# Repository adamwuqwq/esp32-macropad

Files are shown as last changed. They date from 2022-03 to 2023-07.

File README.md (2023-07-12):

# macropad

## Introduction
A low-budget macro numeric keypad based on ESP32 MCU and CH9329 USB HID emulation chip.  

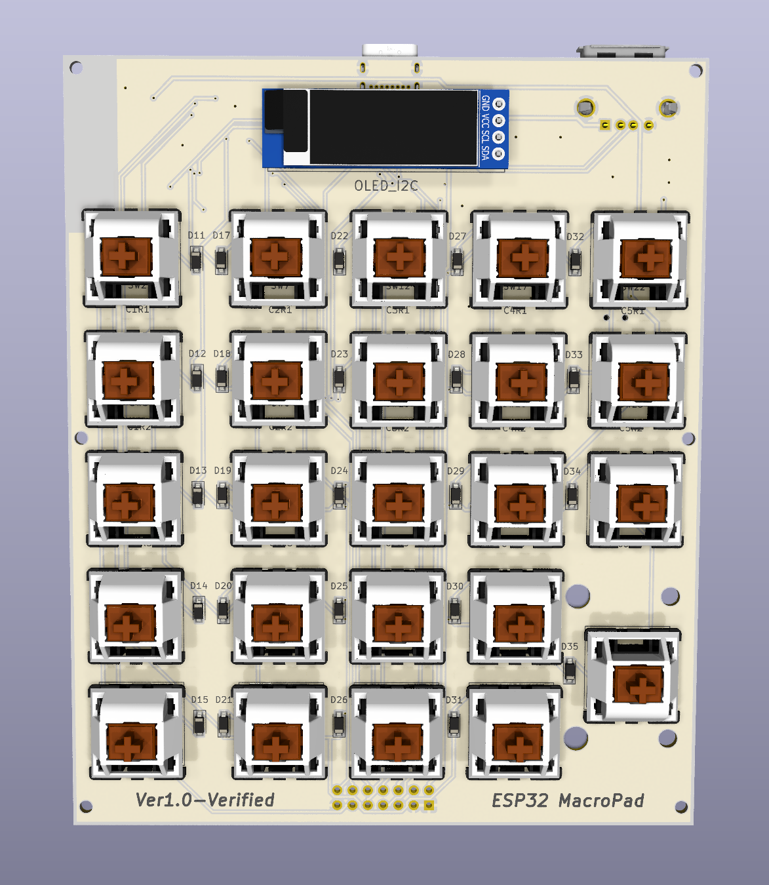
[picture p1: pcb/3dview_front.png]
Image of PCB


## Functions
### Keys and Layout
1. Standard 10-key layout + 5 function keys
2. All key macro support
3. Up to 5 macro profiles (stored in MCU's internal storage)

### Connectivity
1. USB 2.0 HID (CH9329 based) 
2. Built-in USB hub, 1 external USB port, 1 internal USB (based on FE1.1s)
3. USB UART debugging (based on CH340C)
4. Bluetooth 4.2 BLE HID   
5. 2.4GHz Wi-Fi (for configuration and OTA firmware update)

### Power Supply & Power Management
1. 3.7V Li-ion battery charging and management (based on TP5400)
2. Supports MCU's deep sleep and hibernation. 

### UI & User Interaction
1. 0.91' built-in I2C OLED screen
2. Cross-platform configuration App on PC using Qt/PyQt
3. Web configuration interface

### Others
1. USB HID Mouse emulation
2. TBD

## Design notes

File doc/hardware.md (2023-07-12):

# Documentation about the hardware

## System Architecture Diagram
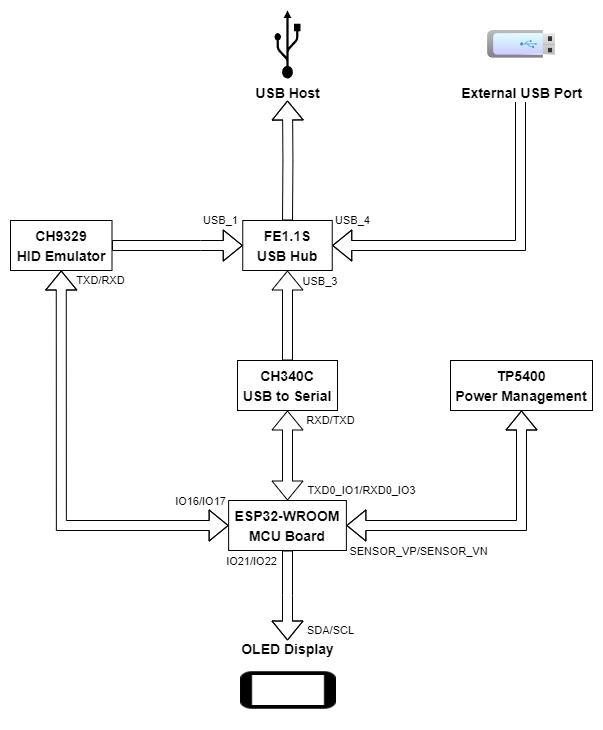
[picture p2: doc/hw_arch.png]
System Architecture


## ESP32 MCU Port Mapping
|Port Name|Connected to|
|--|--|
|KeyMatrix_ROW
|IO27|KeyMatrix row 1|
|IO32|KeyMatrix row 2|
|IO33|KeyMatrix row 3|
|IO25|KeyMatrix row 4|
|IO26|KeyMatrix row 5|
|KeyMatrix_COL
|IO5|KeyMatrix column 1|
|IO18|KeyMatrix column 2|
|IO19|KeyMatrix column 3|
|IO23|KeyMatrix column 4|
|IO4|KeyMatrix column 5|
|OLED_I2C
|IO21|OLED display SDA|
|IO22|OLED display SCL|
|CH9329_HID
|IO16|CH9329 chip TXD|
|IO17|CH9329 chip RXD|
|TP5400_BATT
|SENSOR_VP / IO36|Battery voltage ADC|
|IO39 / SENSOR_VN|Charging indicator|
|CH340_SER
|TXD0 / IO1|CH340 chip RXD|
|RXD0 / IO3|CH340 chip TXD|

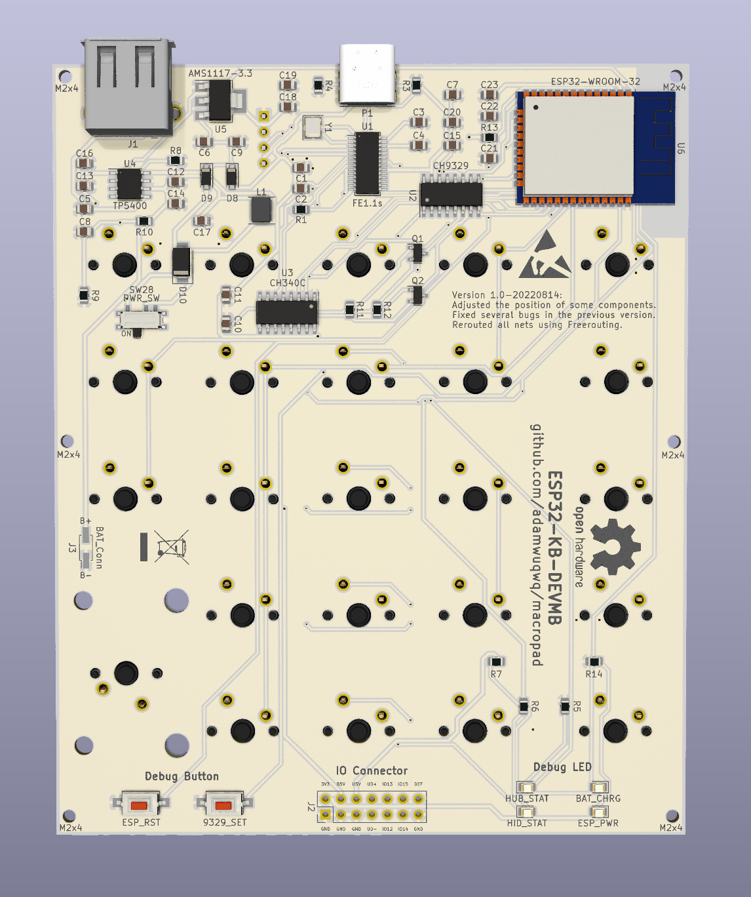
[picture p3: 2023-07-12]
pcb/3dview_back.png

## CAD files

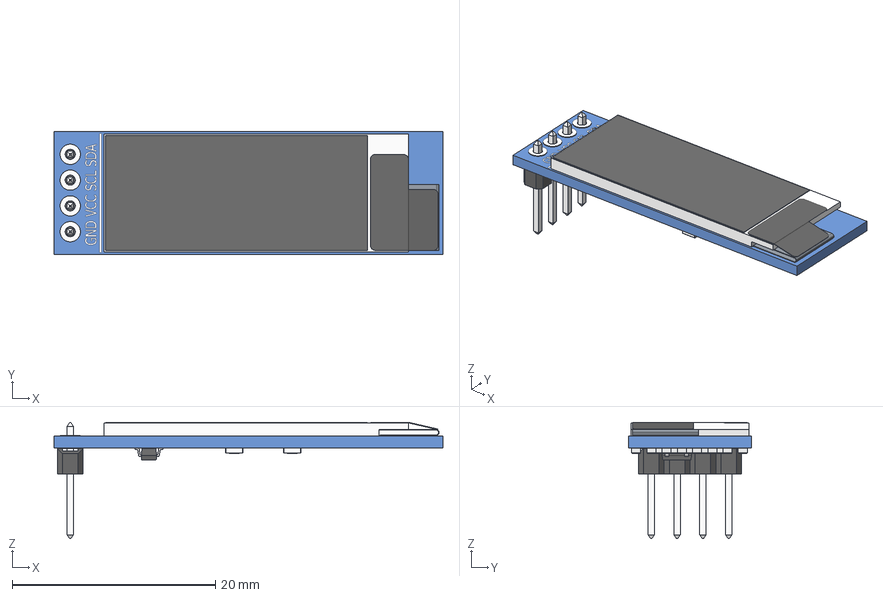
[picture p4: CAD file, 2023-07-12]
pcb/3dmodel/OLED_0.91_128x32.stp
38.3 x 12.1 x 11.5 mm
OLED_0.91_128x32
Pin Header 4 x 1 TH 2.54mm Pitch
RESC-0603 x 13
2SD0601A

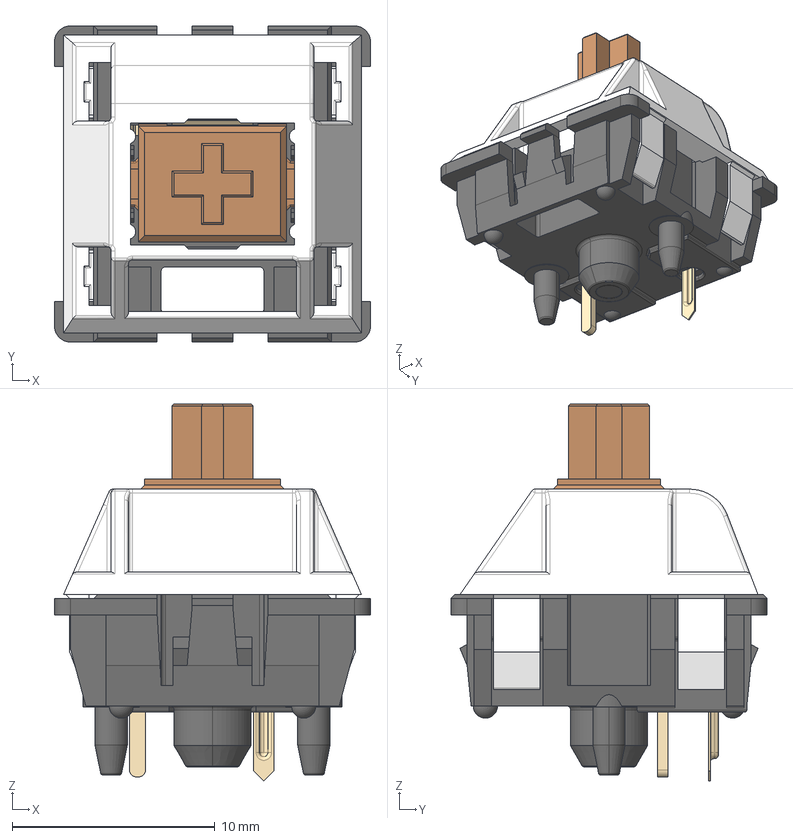
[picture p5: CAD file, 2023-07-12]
pcb/3dmodel/SW_Cherry_MX_PCB.stp
15.6 x 15.6 x 18.6 mm

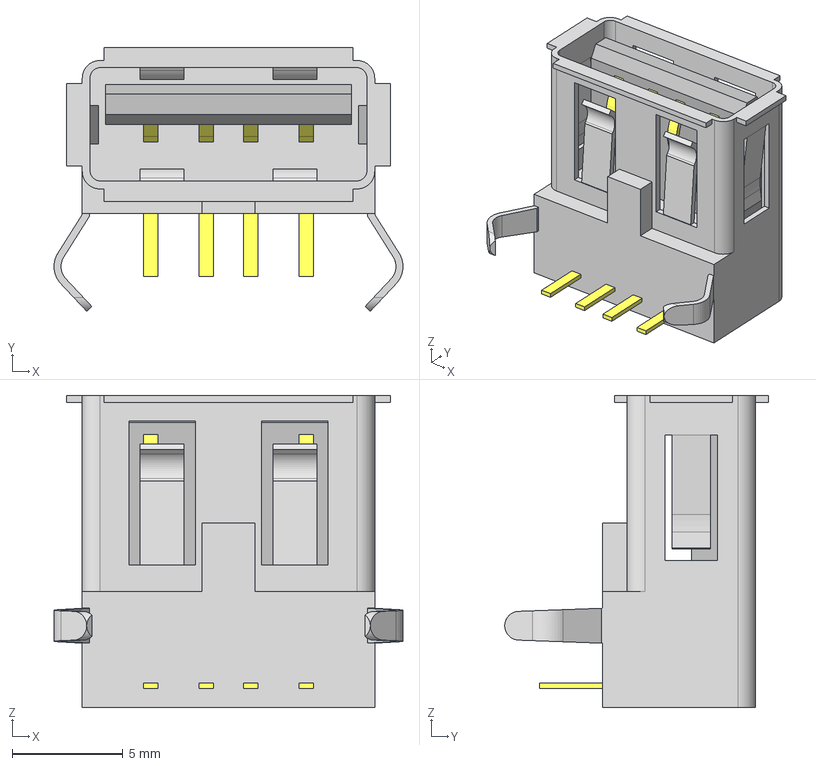
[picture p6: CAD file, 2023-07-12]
pcb/3dmodel/USB-A-S-F-B-TH.stp
15.7 x 11.9 x 14.1 mm
USB-A-S-TH_P
USB-A-S-B-TH_B
USB-A-S-TH_S

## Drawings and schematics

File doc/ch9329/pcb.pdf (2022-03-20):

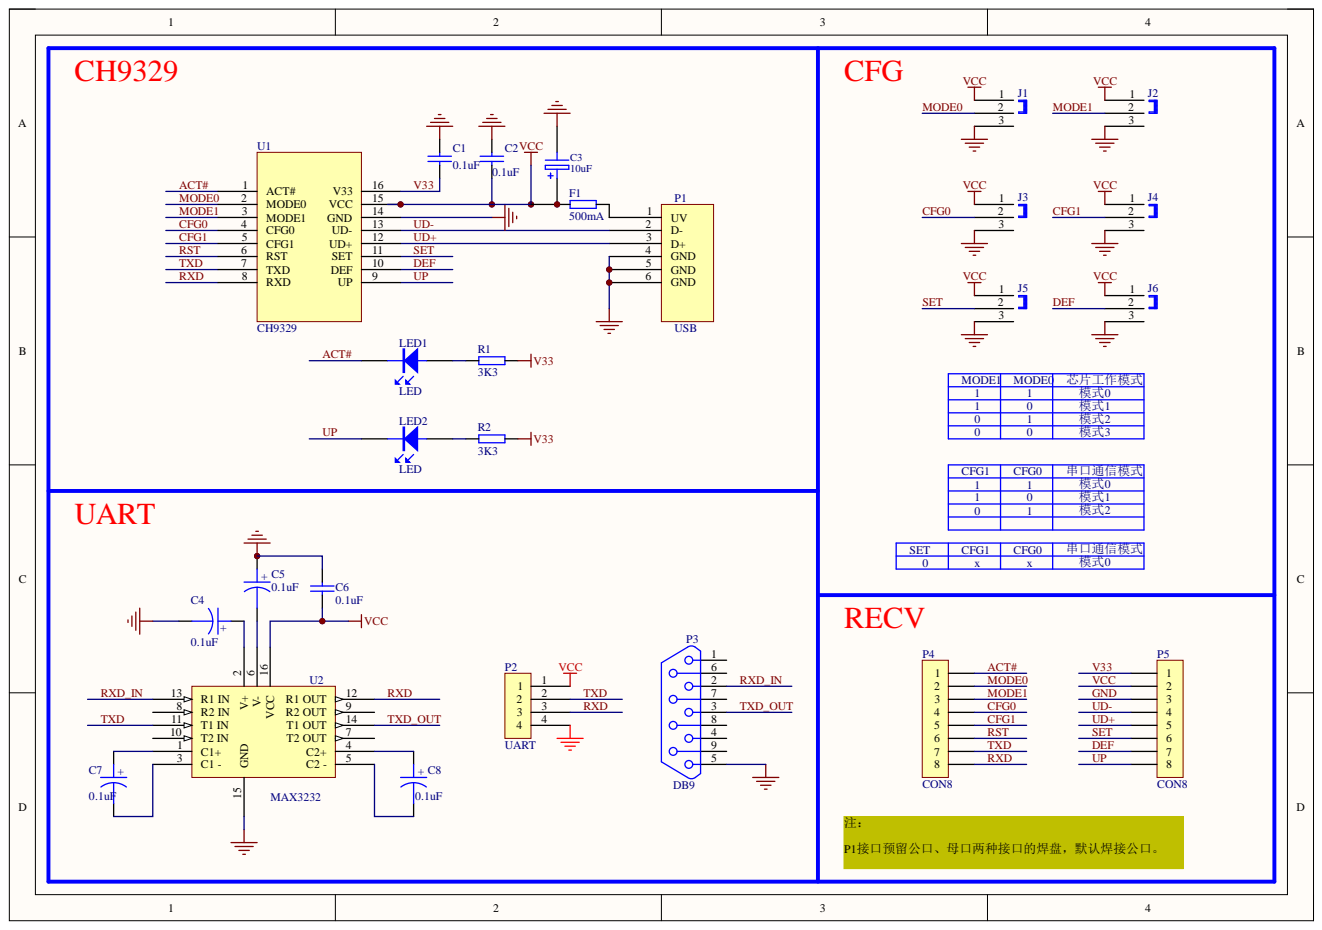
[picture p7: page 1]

MODE1 MODE0 芯片工作模式
1 | 1 | 模式0
1 | 0 | 模式1
0 | 1 | 模式2
0 | 0 | 模式3

CFG1 | CFG0 | 串口通信模式

SET | CFG1 | CFG0 | 串口通信模式
0 | x | x | 模式0

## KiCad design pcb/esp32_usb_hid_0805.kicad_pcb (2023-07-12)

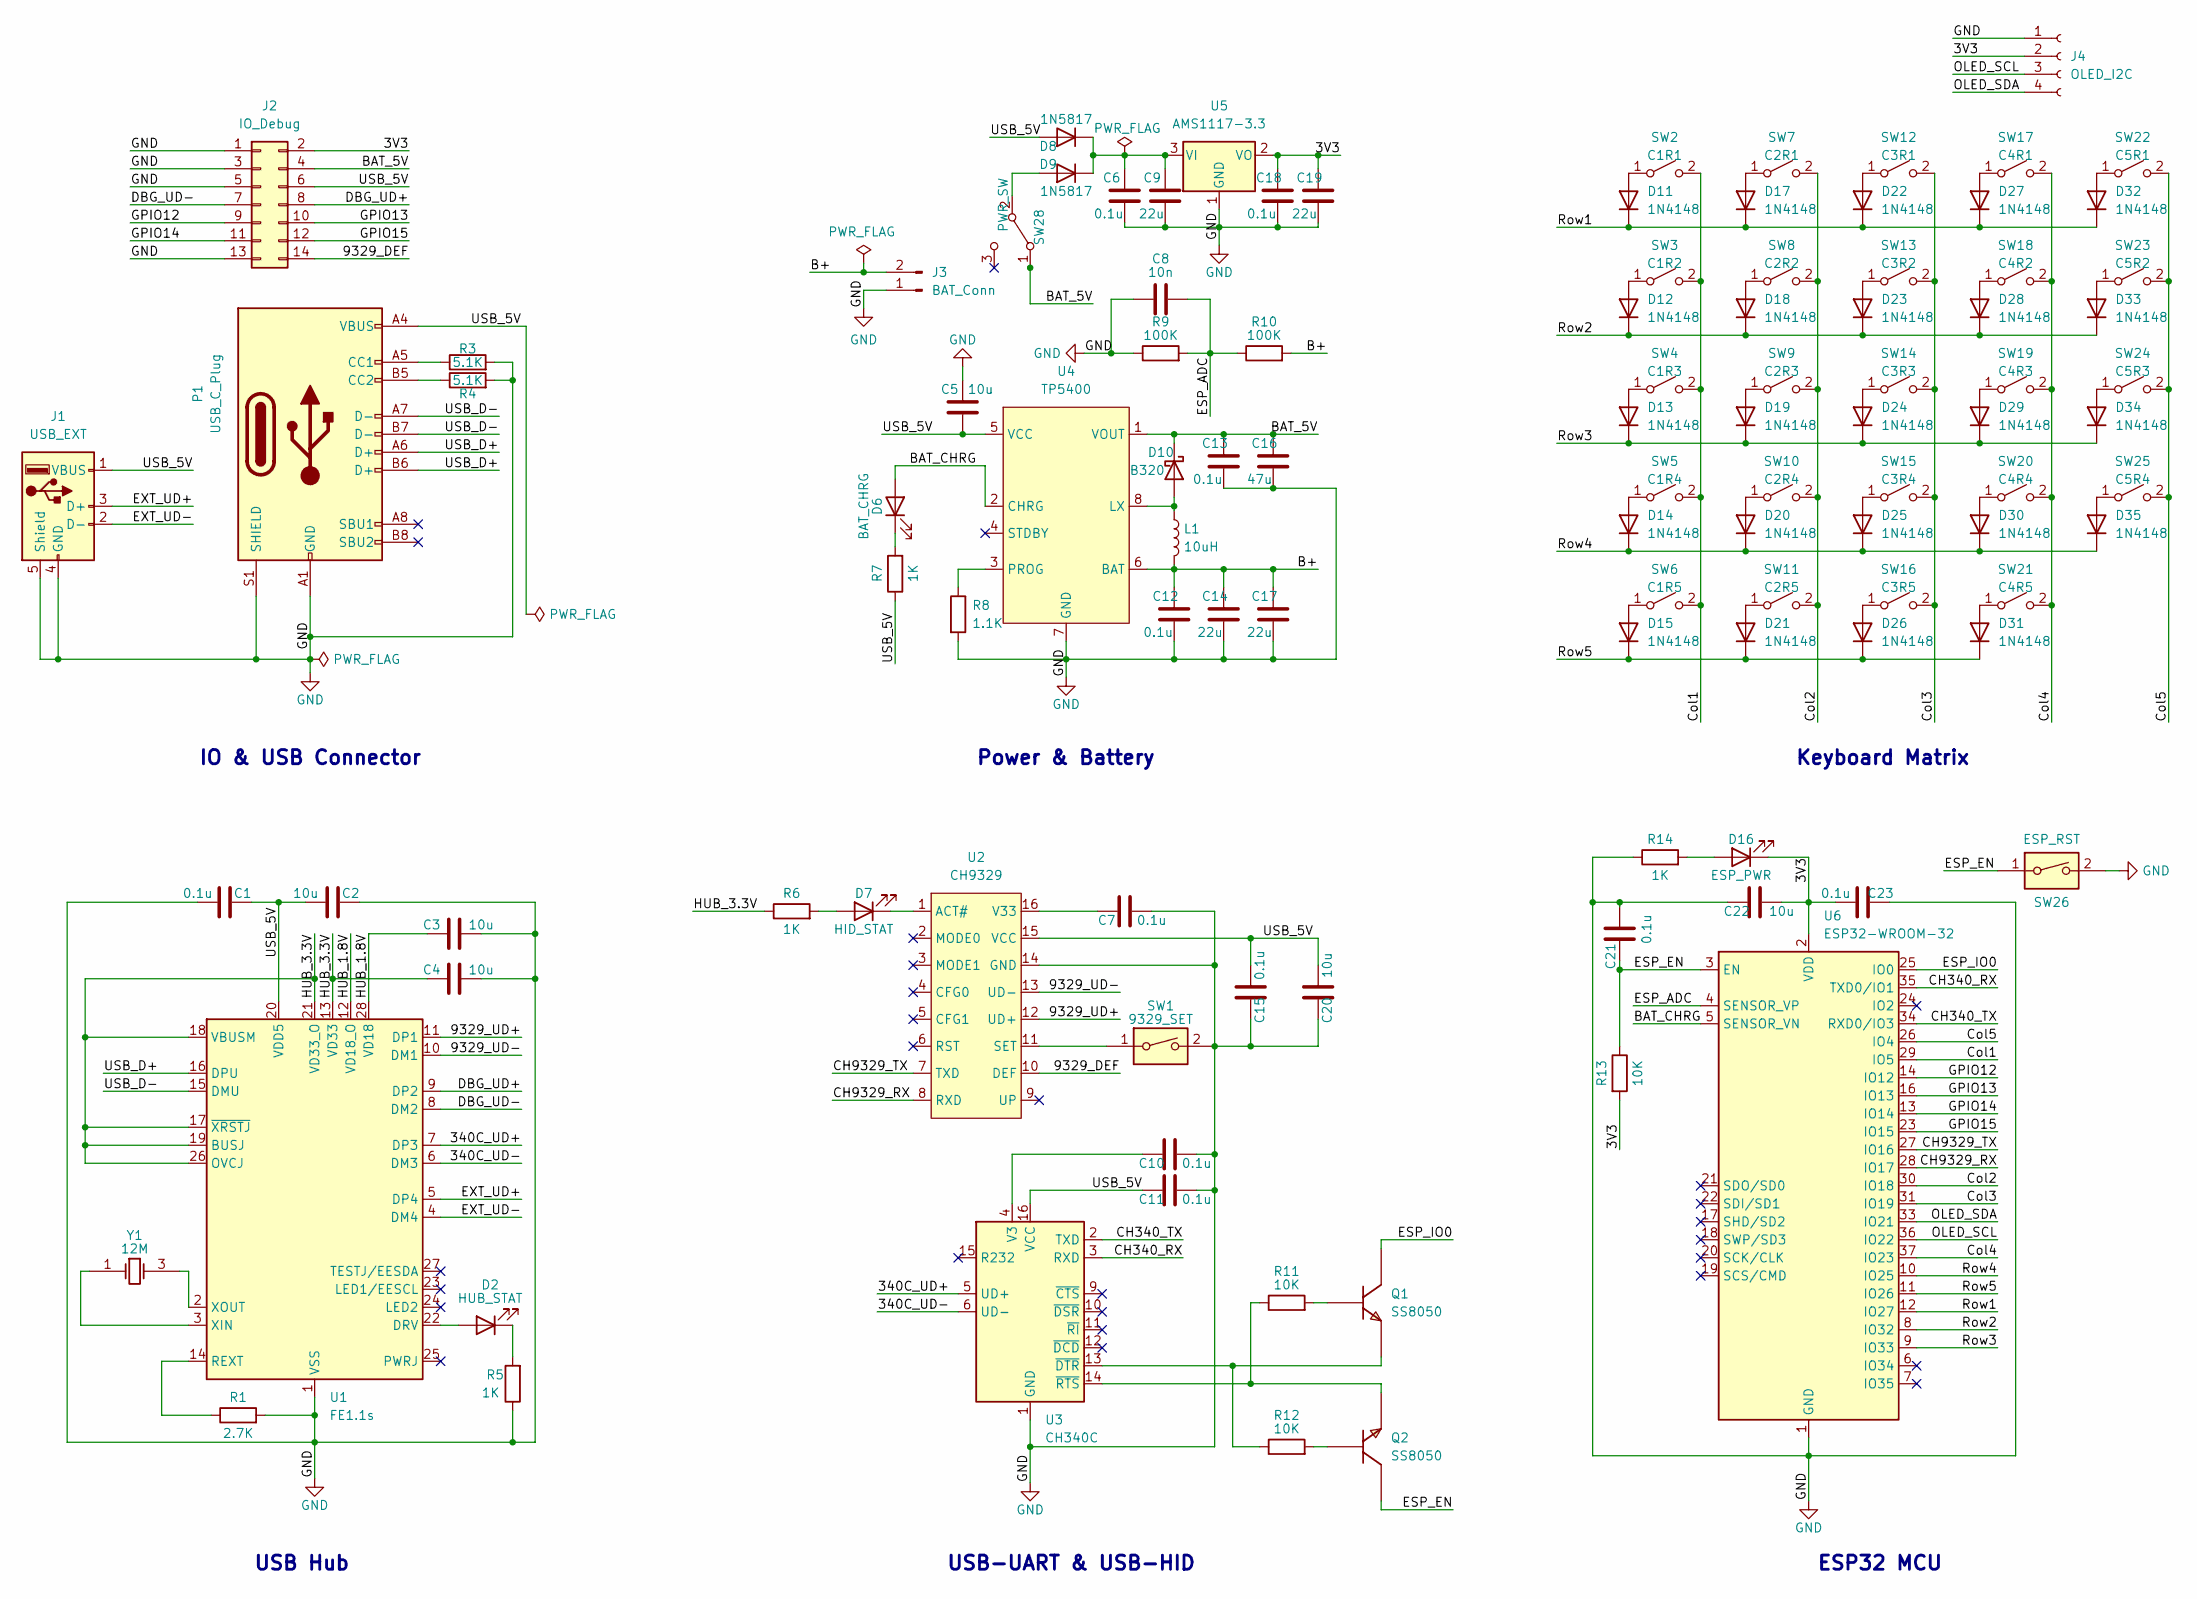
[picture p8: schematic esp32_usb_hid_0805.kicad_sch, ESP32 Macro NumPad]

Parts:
C1, C6, C7, C10, C11, C12, C13, C15, C18, C21, C23: 0.1u; C_0805_2012Metric
C2, C3, C4, C5, C20, C22: 10u; C_0805_2012Metric
C8: 10n; C_0805_2012Metric
C9, C14, C17, C19: 22u; C_0805_2012Metric
C16: 47u; C_0805_2012Metric
D2: HUB_STAT; LED_0805_2012Metric
D6: BAT_CHRG; LED_0805_2012Metric
D7: HID_STAT; LED_0805_2012Metric
D8, D9: 1N5817; D_SOD-123
D10: B320; D_SMA
D11, D12, D13, D14, D15, D17, D18, D19, D20, D21, D22, D23, D24, D25, D26, D27, D28, D29, D30, D31, D32, D33, D34, D35: 1N4148; D_SOD-123
D16: ESP_PWR; LED_0805_2012Metric
J1: USB_EXT; USB_A_Stewart_SS-52100-001_Horizontal
J2: IO_Debug; PinHeader_2x08_P2.54mm_Vertical
J3: BAT_Conn; PinHeader_2x01_P2.00mm_Vertical_SMD
J4: OLED_I2C; PinSocket_1x04_P2.54mm_Vertical
L1: 10uH; L_Coilcraft_XxL4020
P1: USB_C_Plug; USB_C_Receptacle_GCT_USB4085
Q1, Q2: SOT-23_SS8050_Y1; SOT-23
R1: 2.7K; R_0805_2012Metric
R3, R4: 5.1K; R_0805_2012Metric
R5, R6, R7, R14: 1K; R_0805_2012Metric
R8: 1.1K; R_0805_2012Metric
R9, R10: 100K; R_0805_2012Metric
R11, R12, R13: 10K; R_0805_2012Metric
SW1: 9329_SET; SW_SPST_CK_RS282G05A3
SW2: C1R1; SW_Cherry_MX_1.00u_PCB
SW3: C1R2; SW_Cherry_MX_1.00u_PCB
SW4: C1R3; SW_Cherry_MX_1.00u_PCB
SW5: C1R4; SW_Cherry_MX_1.00u_PCB
SW6: C1R5; SW_Cherry_MX_1.00u_PCB
SW7: C2R1; SW_Cherry_MX_1.00u_PCB
SW8: C2R2; SW_Cherry_MX_1.00u_PCB
SW9: C2R3; SW_Cherry_MX_1.00u_PCB
SW10: C2R4; SW_Cherry_MX_1.00u_PCB
SW11: C2R5; SW_Cherry_MX_1.00u_PCB
SW12: C3R1; SW_Cherry_MX_1.00u_PCB
SW13: C3R2; SW_Cherry_MX_1.00u_PCB
SW14: C3R3; SW_Cherry_MX_1.00u_PCB
SW15: C3R4; SW_Cherry_MX_1.00u_PCB
SW16: C3R5; SW_Cherry_MX_1.00u_PCB
SW17: C4R1; SW_Cherry_MX_1.00u_PCB
SW18: C4R2; SW_Cherry_MX_1.00u_PCB
SW19: C4R3; SW_Cherry_MX_1.00u_PCB
SW20: C4R4; SW_Cherry_MX_1.00u_PCB
SW21: C4R5; SW_Cherry_MX_1.00u_PCB
SW22: C5R1; SW_Cherry_MX_1.00u_PCB
SW23: C5R2; SW_Cherry_MX_1.00u_PCB
SW24: C5R3; SW_Cherry_MX_1.00u_PCB
SW25: C5R4; SW_Cherry_MX_2.00u_Vertical_PCB
SW26: ESP_RST; SW_SPST_CK_RS282G05A3
SW28: PWR_SW; SW_SPDT_PCM12
U1: FE1.1s; SSOP-28_3.9x9.9mm_P0.635mm
U2: CH9329; SOP-16_3.9x9.9mm_P1.27mm
U3: CH340C; SOIC-16_3.9x9.9mm_P1.27mm
U4: TP5400; HTSOP-8-1EP_3.9x4.9mm_P1.27mm_EP2.4x3.2mm
U5: AMS1117-3.3; SOT-223-3_TabPin2
U6: ESP32-WROOM-32
Y1: SMD-3225_4P__12MHZ_20PF_10PPM; Crystal_SMD_TXC_7M-4Pin_3.2x2.5mm

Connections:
/3V3: C18.1, C19.1, C22.2, C23.2, D16.1 (K), J2.2, J4.2, R13.2, U5.2 (VO), U6.2 (VDD)
/340C_UD+: U1.7 (DP3), U3.5 (UD+)
/340C_UD-: U1.6 (DM3), U3.6 (UD-)
/9329_DEF: J2.14, U2.10 (DEF)
/9329_UD+: U1.11 (DP1), U2.12 (UD+)
/9329_UD-: U1.10 (DM1), U2.13 (UD-)
/B+: C12.1, C14.1, C17.1, J3.2, L1.2, R10.2, U4.6 (BAT)
/BAT_5V: C13.1, C16.1, D10.1 (K), J2.4, SW28.1 (A), U4.1 (VOUT)
/BAT_CHRG: D6.2 (A), U4.2 (CHRG), U6.5 (SENSOR_VN)
/CH340_RX: U3.3 (RXD), U6.35 (TXD0/IO1)
/CH340_TX: U3.2 (TXD), U6.34 (RXD0/IO3)
/CH9329_RX: U2.8 (RXD), U6.28 (IO17)
/CH9329_TX: U2.7 (TXD), U6.27 (IO16)
/Col1: SW2.2 (B), SW3.2 (B), SW4.2 (B), SW5.2 (B), SW6.2 (B), U6.29 (IO5)
/Col2: SW7.2 (B), SW8.2 (B), SW9.2 (B), SW10.2 (B), SW11.2 (B), U6.30 (IO18)
/Col3: SW12.2 (B), SW13.2 (B), SW14.2 (B), SW15.2 (B), SW16.2 (B), U6.31 (IO19)
/Col4: SW17.2 (B), SW18.2 (B), SW19.2 (B), SW20.2 (B), SW21.2 (B), U6.37 (IO23)
/Col5: SW22.2 (B), SW23.2 (B), SW24.2 (B), SW25.2 (B), U6.26 (IO4)
/DBG_UD+: J2.8, U1.9 (DP2)
/DBG_UD-: J2.7, U1.8 (DM2)
/ESP_ADC: C8.2, R9.2, R10.1, U6.4 (SENSOR_VP)
/ESP_EN: C21.1, Q2.3 (C), R13.1, SW26.1, U6.3 (EN)
/ESP_IO0: Q1.3 (C), U6.25 (IO0)
/EXT_UD+: J1.3 (D+), U1.5 (DP4)
/EXT_UD-: J1.2 (D-), U1.4 (DM4)
/GPIO12: J2.9, U6.14 (IO12)
/GPIO13: J2.10, U6.16 (IO13)
/GPIO14: J2.11, U6.13 (IO14)
/GPIO15: J2.12, U6.23 (IO15)
/HUB_1.8V: C3.1, U1.12 (VD18_O), U1.28 (VD18)
/HUB_3.3V: C4.1, R6.1, U1.13 (VD33), U1.17 (~XRSTJ), U1.18 (VBUSM), U1.19 (BUSJ), U1.21 (VD33_O), U1.26 (OVCJ)
/OLED_SCL: J4.3, U6.36 (IO22)
/OLED_SDA: J4.4, U6.33 (IO21)
/Row1: D11.1 (K), D17.1 (K), D22.1 (K), D27.1 (K), D32.1 (K), U6.12 (IO27)
/Row2: D12.1 (K), D18.1 (K), D23.1 (K), D28.1 (K), D33.1 (K), U6.8 (IO32)
/Row3: D13.1 (K), D19.1 (K), D24.1 (K), D29.1 (K), D34.1 (K), U6.9 (IO33)
/Row4: D14.1 (K), D20.1 (K), D25.1 (K), D30.1 (K), D35.1 (K), U6.10 (IO25)
/Row5: D15.1 (K), D21.1 (K), D26.1 (K), D31.1 (K), U6.11 (IO26)
/USB_5V: C1.1, C2.2, C5.2, C11.2, C15.2, C20.2, D8.2 (A), J1.1 (VBUS), J2.6, P1.A4 (VBUS), P1.A9 (VBUS), P1.B4 (VBUS), P1.B9 (VBUS), R7.1, U1.20 (VDD5), U2.15 (VCC), U3.16 (VCC), U4.5 (VCC)
/USB_D+: P1.A6 (D+), P1.B6 (D+), U1.16 (DPU)
/USB_D-: P1.A7 (D-), P1.B7 (D-), U1.15 (DMU)
GND: C1.2, C2.1, C3.2, C4.2, C5.1, C6.2, C7.2, C8.1, C9.2, C10.2, C11.1, C12.2, C13.2, C14.2, C15.1, C16.2, C17.2, C18.2, C19.2, C20.1, C21.2, C22.1, C23.1, J1.4 (GND), J1.5 (Shield), J2.1, J2.3, J2.5, J2.13, J3.1, J4.1, P1.A1 (GND), P1.A12 (GND), P1.B1 (GND), P1.B12 (GND), P1.S1 (SHIELD), R1.2, R3.2, R4.2, R5.1, R8.2, R9.1, R14.1, SW1.2, SW26.2, U1.1 (VSS), U2.14 (GND), U3.1 (GND), U4.7 (GND), U5.1 (GND), U6.1 (GND), U6.15 (GND), U6.38 (GND), U6.39 (GND)
unnamed: C6.1, C9.1, D8.1 (K), D9.1 (K), U5.3 (VI)
unnamed: C7.1, U2.16 (V33)
unnamed: C10.1, U3.4 (V3)
unnamed: D2.1 (K), R5.2
unnamed: D2.2 (A), U1.22 (DRV)
unnamed: D7.1 (K), U2.1 (ACT#)
unnamed: D7.2 (A), R6.2
unnamed: D9.2 (A), SW28.2 (B)
unnamed: D10.2 (A), L1.1, U4.8 (LX)
unnamed: D11.2 (A), SW2.1 (A)
unnamed: D12.2 (A), SW3.1 (A)
unnamed: D13.2 (A), SW4.1 (A)
unnamed: D14.2 (A), SW5.1 (A)
unnamed: D15.2 (A), SW6.1 (A)
unnamed: D16.2 (A), R14.2
unnamed: D17.2 (A), SW7.1 (A)
unnamed: D18.2 (A), SW8.1 (A)
unnamed: D19.2 (A), SW9.1 (A)
unnamed: D20.2 (A), SW10.1 (A)
unnamed: D21.2 (A), SW11.1 (A)
unnamed: D22.2 (A), SW12.1 (A)
unnamed: D23.2 (A), SW13.1 (A)
unnamed: D24.2 (A), SW14.1 (A)
unnamed: D25.2 (A), SW15.1 (A)
unnamed: D26.2 (A), SW16.1 (A)
unnamed: D27.2 (A), SW17.1 (A)
unnamed: D28.2 (A), SW18.1 (A)
unnamed: D29.2 (A), SW19.1 (A)
unnamed: D30.2 (A), SW20.1 (A)
unnamed: D31.2 (A), SW21.1 (A)
unnamed: D32.2 (A), SW22.1 (A)
unnamed: D33.2 (A), SW23.1 (A)
unnamed: D34.2 (A), SW24.1 (A)
unnamed: D35.2 (A), SW25.1 (A)
unnamed: P1.A5 (CC1), R3.1
unnamed: P1.B5 (CC2), R4.1
unnamed: Q1.1 (B), R11.2
unnamed: Q1.2 (E), R12.1, U3.13 (~DTR)
unnamed: Q2.1 (B), R12.2
unnamed: Q2.2 (E), R11.1, U3.14 (~RTS)
unnamed: R1.1, U1.14 (REXT)
unnamed: D6.1 (K), R7.2
unnamed: R8.1, U4.3 (PROG)
unnamed: SW1.1, U2.11 (SET)
unnamed: U1.2 (XOUT), Y1.3 (OSC2)
unnamed: U1.3 (XIN), Y1.1 (OSC1)

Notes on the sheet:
USB Hub
Keyboard Matrix
USB-UART & USB-HID
Power & Battery
IO & USB Connector
ESP32 MCU

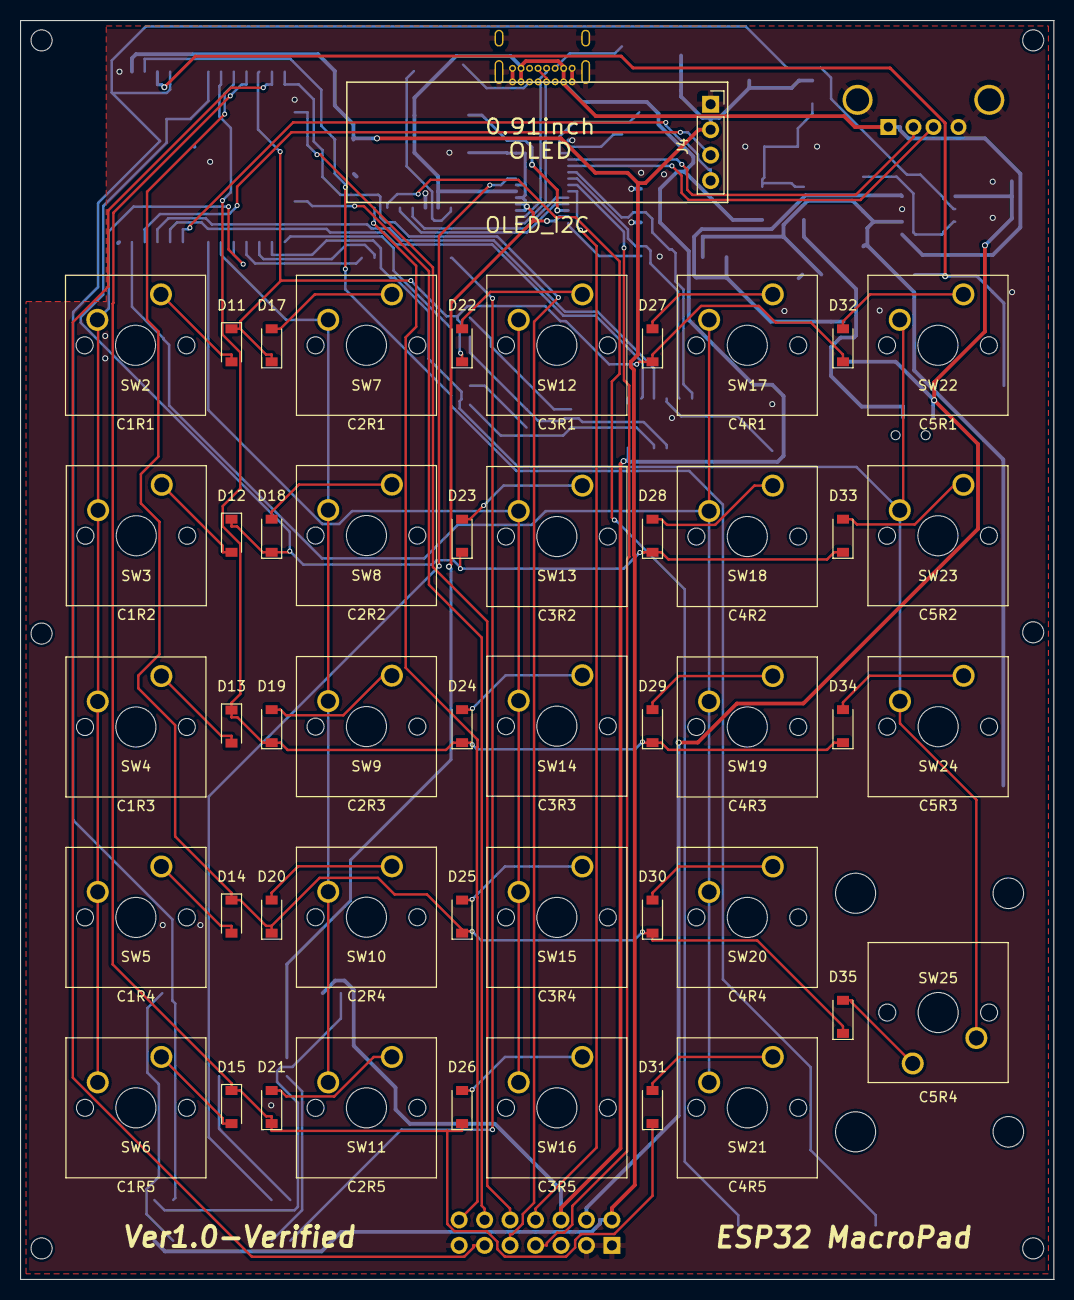
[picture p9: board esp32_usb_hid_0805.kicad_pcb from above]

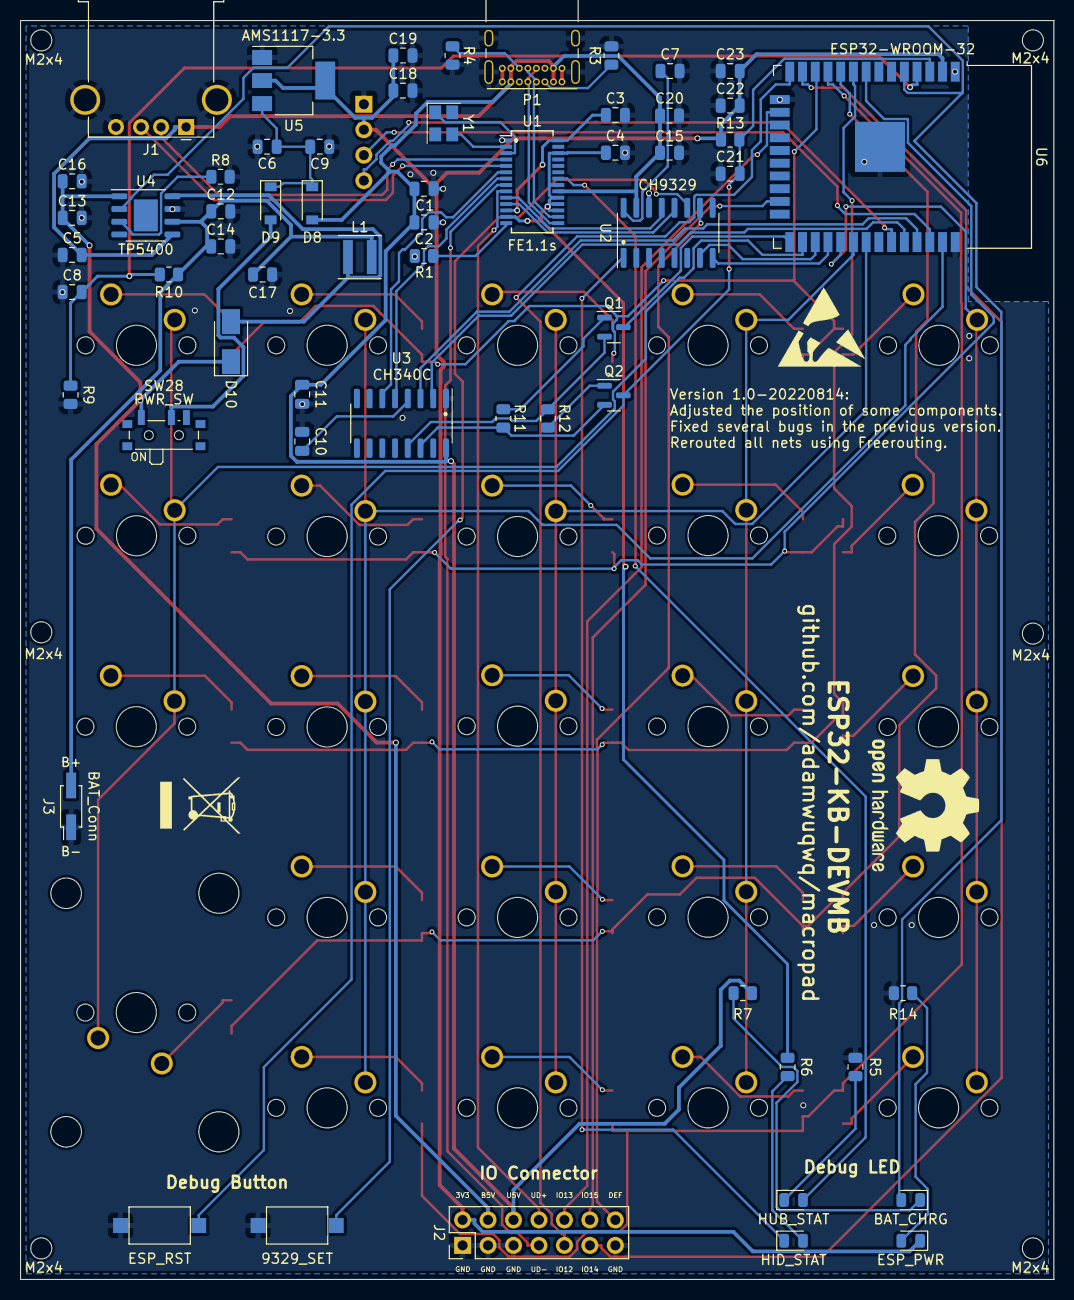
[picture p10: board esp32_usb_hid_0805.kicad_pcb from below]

Board: 2 copper layers, 103.1 x 125.6 mm, 109 parts (60 on the bottom side), 88 nets.

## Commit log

2022-03-20 Created KiCAD project files, added documents and tools for CH9329
    [esp8266_test_initial.kicad_pcb, esp8266_test_initial.kicad_sch]
2022-03-28 Updated ESP8266_test_initial's kiCAD PCB file
    [esp8266_test_initial.kicad_pcb, esp8266_test_initial.kicad_sch]
2022-04-06 Added datasheet for esp32,fe1.1s,tp5400,ch340c,ams1117
2022-04-06 Updated KiCAD Schematic and PCB file, version 0.4-alpha
    [esp8266_test_initial.kicad_pcb, esp8266_test_initial.kicad_sch]
2022-04-06 Updated readme file: ESP8266 -> ESP32
2023-07-12 Update PCB design
    [OLED_0.91_128x32.stp, SW_Cherry_MX_PCB.stp, USB-A-S-F-B-TH.stp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]

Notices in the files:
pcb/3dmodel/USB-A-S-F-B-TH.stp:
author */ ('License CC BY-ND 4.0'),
